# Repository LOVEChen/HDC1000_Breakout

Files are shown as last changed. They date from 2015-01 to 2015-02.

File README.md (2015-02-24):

HDC1000 Breakout Board
======================

Here are Eagle files for my HDC1000 Breakout Board. It should work with the HDC1008 too, but I haven't tested it.

<p align="center">
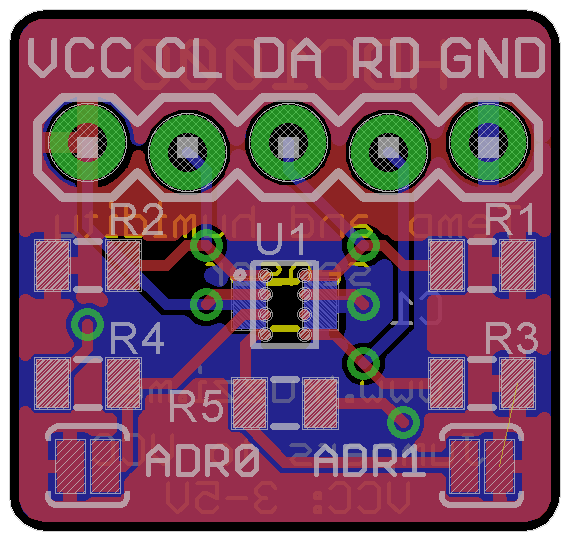
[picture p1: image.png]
  
</p>

The HDC1000 is a digital humidity sensor with integrated temperature sensor. 

More info and datasheet: http://www.ti.com/product/HDC1000.

Arduino library: https://github.com/ftruzzi/HDC1000-Arduino.

Blog post: http://b.truzzi.me/hdc1000-temperature-and-humidity-sensor-breakout-with-arduino-library/

##Features and parts list:

* **U1:** HDC1000 IC from Texas Instruments, DSBGA-8 package.
* **C1:** 0.1uF 0805 package decoupling cap.
* **R1,R2:** 4.7k-10k ohm, 0805 package. I2C pull-up resistors.
* **R3:** 10k ohm, 0805 package. Pull-up resistor to VCC, for the DRDYN pin. Leave the pin floating if not used.
* **R4, R5:** 10k ohm, pull-down resistors to GND for address selection.
* **ADR0, ADR1** solder jumpers to VCC, connect to change the chip address (default: 0x41).

You can visit my website at www.truzzi.me.

Any suggestions or comments are appreciated!

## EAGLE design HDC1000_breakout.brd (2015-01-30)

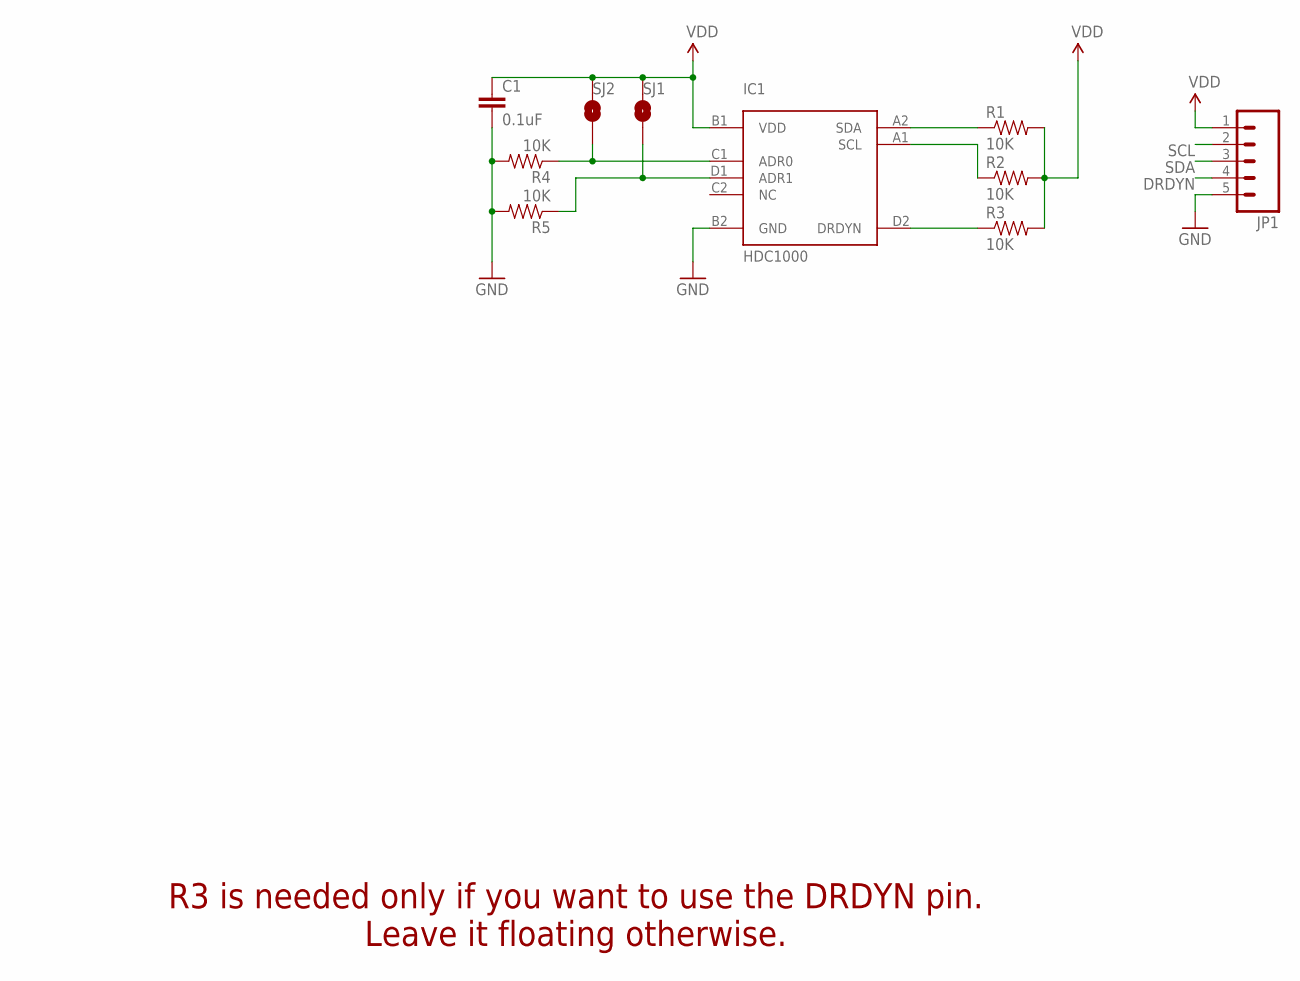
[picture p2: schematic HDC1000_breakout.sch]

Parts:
C1: 0.1uF; 0805
IC1: HDC1000; DSBGA_8_YPA
JP1: M05LOCK; 1X05_LOCK
R1, R2, R3, R4, R5: 10K; 0805
SJ1, SJ2: SOLDERJUMPERNO; SJ_2S-NO

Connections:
DRDYN: IC1.D2 (DRDYN), JP1.4, R3.1
GND: C1.2, IC1.B2 (GND), JP1.5, R4.2, R5.2
unnamed: IC1.D1 (ADR1), R5.1, SJ1.2
unnamed: IC1.C1 (ADR0), R4.1, SJ2.2
SCL: IC1.A1 (SCL), JP1.2, R2.1
SDA: IC1.A2 (SDA), JP1.3, R1.1
VDD: C1.1, IC1.B1 (VDD), JP1.1, R1.2, R2.2, R3.2, SJ1.1, SJ2.1

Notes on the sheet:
R3 is needed only if you want to use the DRDYN pin. Leave it floating otherwise.

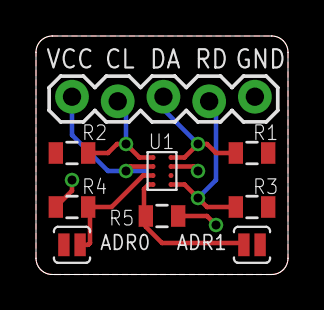
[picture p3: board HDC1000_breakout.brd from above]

Board: 2 copper layers, 14.0 x 13.2 mm, 10 parts (1 on the bottom side), 7 nets.

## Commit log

2015-01-30 First release.
    [HDC1000_breakout.brd, HDC1000_breakout.sch]
2015-01-30 Fixed VCC plane.
    [HDC1000_breakout.brd]

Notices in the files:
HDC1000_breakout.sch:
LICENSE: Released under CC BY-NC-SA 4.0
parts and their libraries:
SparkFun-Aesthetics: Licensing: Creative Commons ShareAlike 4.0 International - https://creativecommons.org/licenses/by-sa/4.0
